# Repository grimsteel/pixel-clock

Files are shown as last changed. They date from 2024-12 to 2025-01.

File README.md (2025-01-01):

# The Pixel Clock

A clock-shaped PCB with 8 Neopixels and a buzzer. Built on a `CH552` MCU. Powered by two rechargeable LIR2032s.

Although this cannot actually be used as a clock, it can be used to play songs, with the neopixels flashing in sync.

Firmware using [ch554_sdcc](https://github.com/Blinkinlabs/ch554_sdcc) is in the firmware directory.

[gerber.zip](https://gerber.zip/2d/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)

---

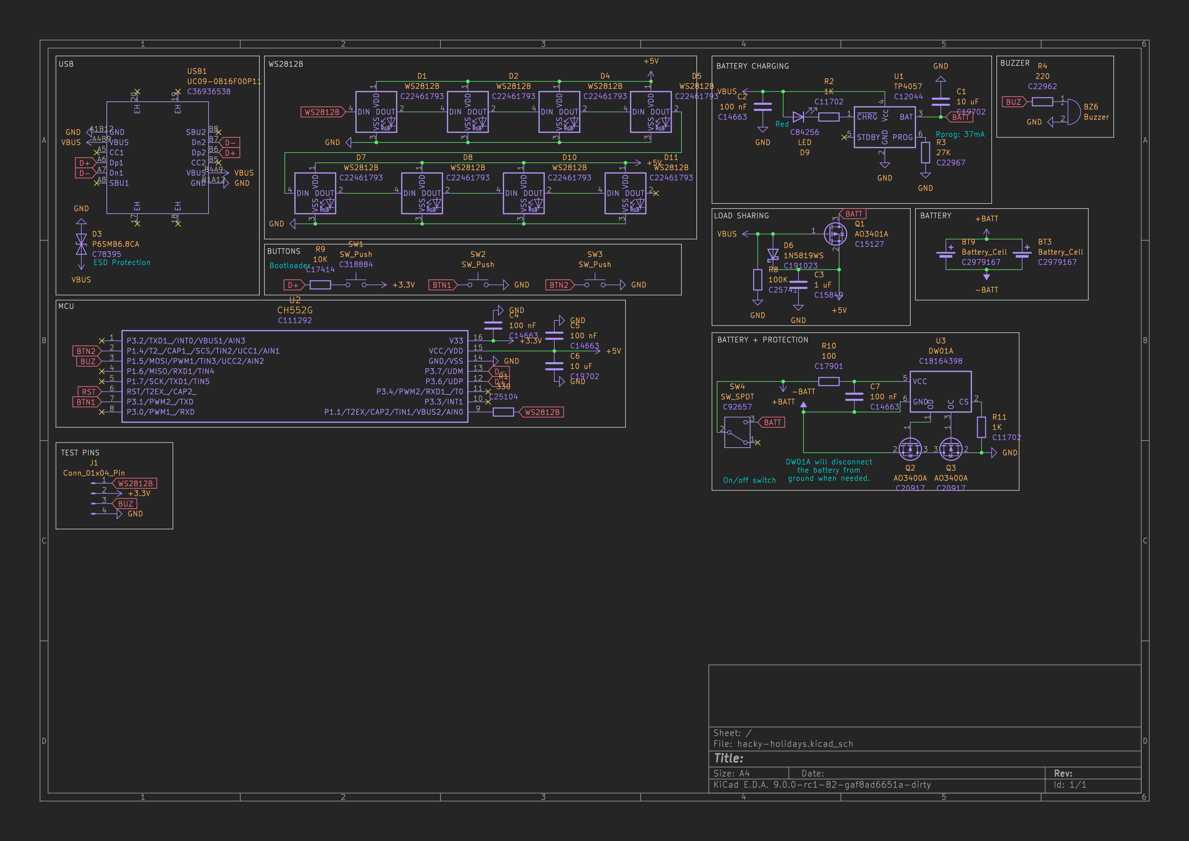
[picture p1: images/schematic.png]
schematic


gerber - top
gerber - bottom

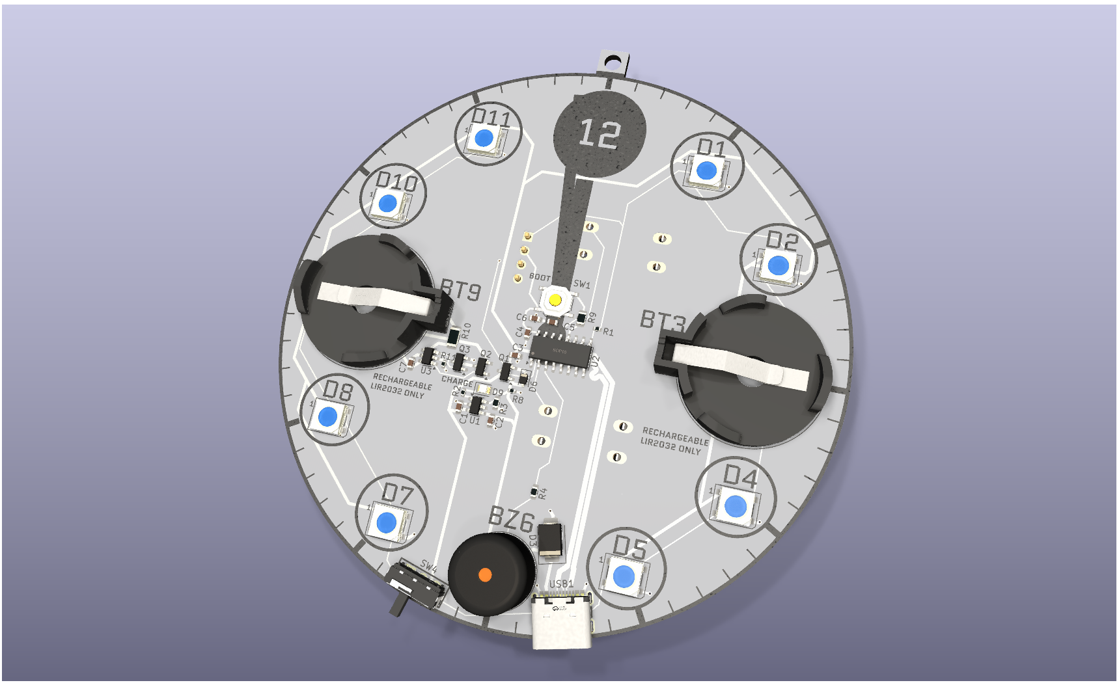
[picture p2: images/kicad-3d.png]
kicad 3d


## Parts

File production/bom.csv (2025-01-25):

Designator | Footprint | Quantity | Value | LCSC Part #
BT3, BT9 | BatteryHolder_MYOUNG_BS-07-A1BJ001_CR2032 | 2 | Battery_Cell | C2979167
C1, C6 | 0603 | 2 | 10 uF | C19702
C2, C4, C5, C7 | 0603 | 4 | 100 nF | C14663
C3 | 0603 | 1 | 1 uF | C15849
D1, D10, D11, D2, D4, D5, D7, D8 | LED-SMD_4P-L1.6-W1.5_XL-1615RGBC-WS2812B | 8 | WS2812B | C5349954
D3 | D_SMB | 1 | P6SMB6.8CA | C78395
D6 | D_SOD-323 | 1 | 1N5819WS | C191023
D9 | 0805 | 1 | LED | C84256
Q1 | SOT-23 | 1 | AO3401A | C15127
Q2, Q3 | SOT-23 | 2 | AO3400A | C20917
R1 | 0402 | 1 | 330 | C25104
R10 | 1206 | 1 | 100 | C17901
R11, R2 | 0402 | 2 | 1K | C11702
R3 | 0603 | 1 | 27K | C22967
R4 | 0603 | 1 | 220 | C22962
R5, R6 | 0603 | 2 | 5.1K | C23186
R8 | 0402 | 1 | 100K | C25741
R9 | 0805 | 1 | 10K | C17414
SW1 | SW_Push_1P1T_XKB_TS-1187A | 1 | SW_Push | C318884
U1 | SOT-23-6 | 1 | TP4057 | C12044
U2 | STC_SOP-16_3.9x9.9mm_P1.27mm | 1 | CH552G | C111292
U3 | SOT-23-6 | 1 | DW01A | C18164398
USB1 | USB-C_UC09-0B16F00P11 | 1 | UC09-0B16F00P11 | C36936538

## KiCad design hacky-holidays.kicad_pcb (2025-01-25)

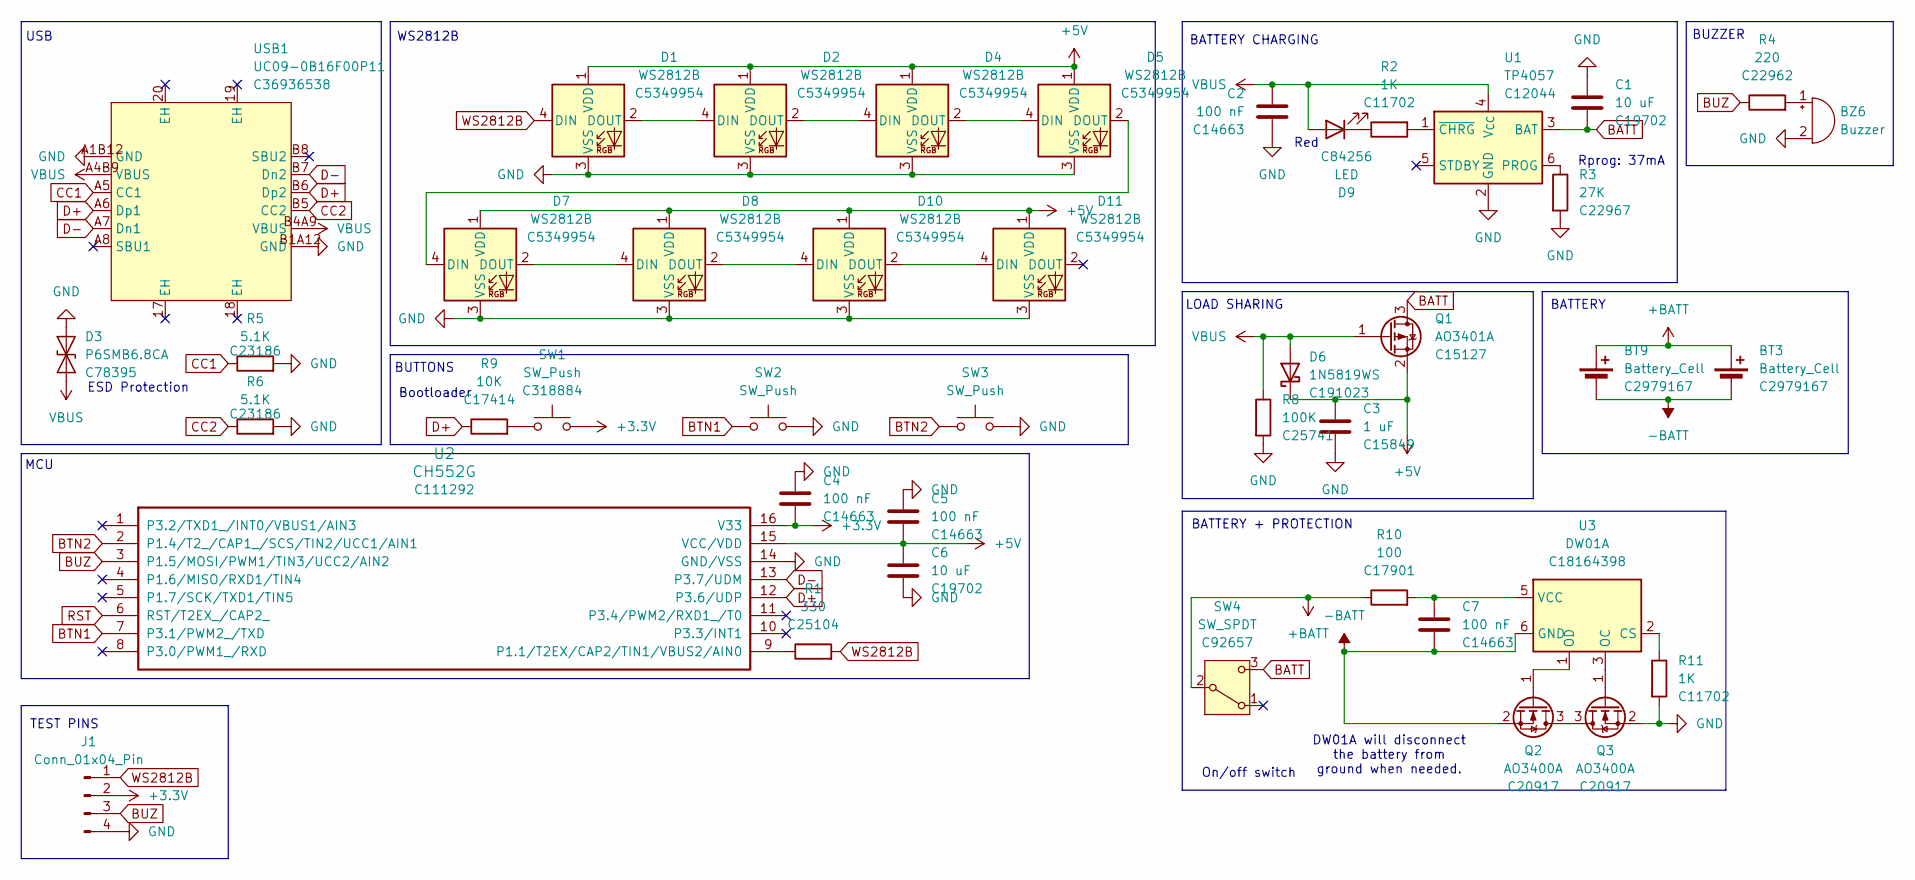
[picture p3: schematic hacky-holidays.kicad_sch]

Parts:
BT3, BT9: Battery_Cell; BatteryHolder_MYOUNG_BS-07-A1BJ001_CR2032; LCSC C2979167
BZ6: Buzzer; Buzzer_12x9.5RM7.6
C1, C6: 10 uF; C_0603_1608Metric; LCSC C19702
C2, C4, C5, C7: 100 nF; C_0603_1608Metric; LCSC C14663
C3: 1 uF; C_0603_1608Metric; LCSC C15849
D1, D2, D4, D5, D7, D8, D10, D11: WS2812B; LED-SMD_4P-L1.6-W1.5_XL-1615RGBC-WS2812B; LCSC C5349954
D3: P6SMB6.8CA; D_SMB; LCSC C78395
D6: 1N5819WS; D_SOD-323; LCSC C191023
D9: LED; LED_0805_2012Metric; LCSC C84256
J1: Conn_01x04_Pin; PinHeader_1x04_P2.54mm_Vertical
Q1: AO3401A; SOT-23; LCSC C15127
Q2, Q3: AO3400A; SOT-23; LCSC C20917
R1: 330; R_0402_1005Metric; LCSC C25104
R2, R11: 1K; R_0402_1005Metric; LCSC C11702
R3: 27K; R_0603_1608Metric; LCSC C22967
R4: 220; R_0603_1608Metric; LCSC C22962
R5, R6: 5.1K; R_0603_1608Metric; LCSC C23186
R8: 100K; R_0402_1005Metric; LCSC C25741
R9: 10K; R_0805_2012Metric; LCSC C17414
R10: 100; R_1206_3216Metric; LCSC C17901
SW1: SW_Push; SW_Push_1P1T_XKB_TS-1187A; LCSC C318884
SW2, SW3: SW_Push; SW_PUSH-12mm
SW4: SW_SPDT; SW-TH_K3-1260D-L1; LCSC C92657
U1: TP4057; SOT-23-6; LCSC C12044
U2: CH552G; STC_SOP-16_3.9x9.9mm_P1.27mm; LCSC C111292
U3: DW01A; SOT-23-6; LCSC C18164398
USB1: UC09-0B16F00P11; USB-C_UC09-0B16F00P11; LCSC Part C36936538

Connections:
+3.3V: C4.2, J1.2, SW1.2, U2.16 (V33)
+5V: C3.1, C5.1, C6.2, D1.1 (VDD), D2.1 (VDD), D4.1 (VDD), D5.1 (VDD), D6.1 (K), D7.1 (VDD), D8.1 (VDD), D10.1 (VDD), D11.1 (VDD), Q1.2 (S), U2.15 (VCC/VDD)
+BATT: BT3.1 (+), BT9.1 (+), R10.1, SW4.2 (B)
-BATT: BT3.2 (-), BT9.2 (-), C7.2, Q2.2 (S), U3.6 (GND)
BATT: C1.2, Q1.3 (D), SW4.3 (C), U1.3 (BAT)
BTN1: SW2.1, U2.7 (P3.1/PWM2_/TXD)
BTN2: SW3.1, U2.2 (P1.4/T2_/CAP1_/SCS/TIN2/UCC1/AIN1)
BUZ: J1.3, R4.1, U2.3 (P1.5/MOSI/PWM1/TIN3/UCC2/AIN2)
CC1: R5.1, USB1.A5 (CC1)
CC2: R6.1, USB1.B5 (CC2)
D+: R9.1, U2.12 (P3.6/UDP), USB1.A6 (Dp1), USB1.B6 (Dp2)
D-: U2.13 (P3.7/UDM), USB1.A7 (Dn1), USB1.B7 (Dn2)
GND: BZ6.2 (-), C1.1, C2.2, C3.2, C4.1, C5.2, C6.1, D1.3 (VSS), D2.3 (VSS), D3.2 (A2), D4.3 (VSS), D5.3 (VSS), D7.3 (VSS), D8.3 (VSS), D10.3 (VSS), D11.3 (VSS), J1.4, Q3.2 (S), R3.2, R5.2, R6.2, R8.2, R11.2, SW2.2, SW3.2, U1.2 (GND), U2.14 (GND/VSS), USB1.A1B12 (GND), USB1.B1A12 (GND)
unnamed: BZ6.1 (+), R4.2
unnamed: D1.2 (DOUT), D2.4 (DIN)
unnamed: D2.2 (DOUT), D4.4 (DIN)
unnamed: D4.2 (DOUT), D5.4 (DIN)
unnamed: D5.2 (DOUT), D7.4 (DIN)
unnamed: D7.2 (DOUT), D8.4 (DIN)
unnamed: D9.1 (K), R2.1
unnamed: D8.2 (DOUT), D10.4 (DIN)
unnamed: D10.2 (DOUT), D11.4 (DIN)
unnamed: Q2.3 (D), Q3.3 (D)
unnamed: Q2.1 (G), U3.1 (OD)
unnamed: Q3.1 (G), U3.3 (OC)
unnamed: R9.2, SW1.1
unnamed: R3.1, U1.6 (PROG)
unnamed: R2.2, U1.1 (~CHRG)
unnamed: R1.1, U2.9 (P1.1/T2EX/CAP2/TIN1/VBUS2/AIN0)
unnamed: R11.1, U3.2 (CS)
unnamed: C7.1, R10.2, U3.5 (VCC)
RST: U2.6 (RST/T2EX_/CAP2_)
VBUS: C2.1, D3.1 (A1), D6.2 (A), D9.2 (A), Q1.1 (G), R8.1, U1.4 (V_{CC}), USB1.A4B9 (VBUS), USB1.B4A9 (VBUS)
WS2812B: D1.4 (DIN), J1.1, R1.2

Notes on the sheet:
Bootloader
On/off switch
MCU
BATTERY
DW01A will disconnect the battery from ground when needed.
Rprog: 37mA
BUZZER
Red
USB
BUTTONS
BATTERY CHARGING
BATTERY + PROTECTION
TEST PINS
LOAD SHARING
WS2812B
ESD Protection

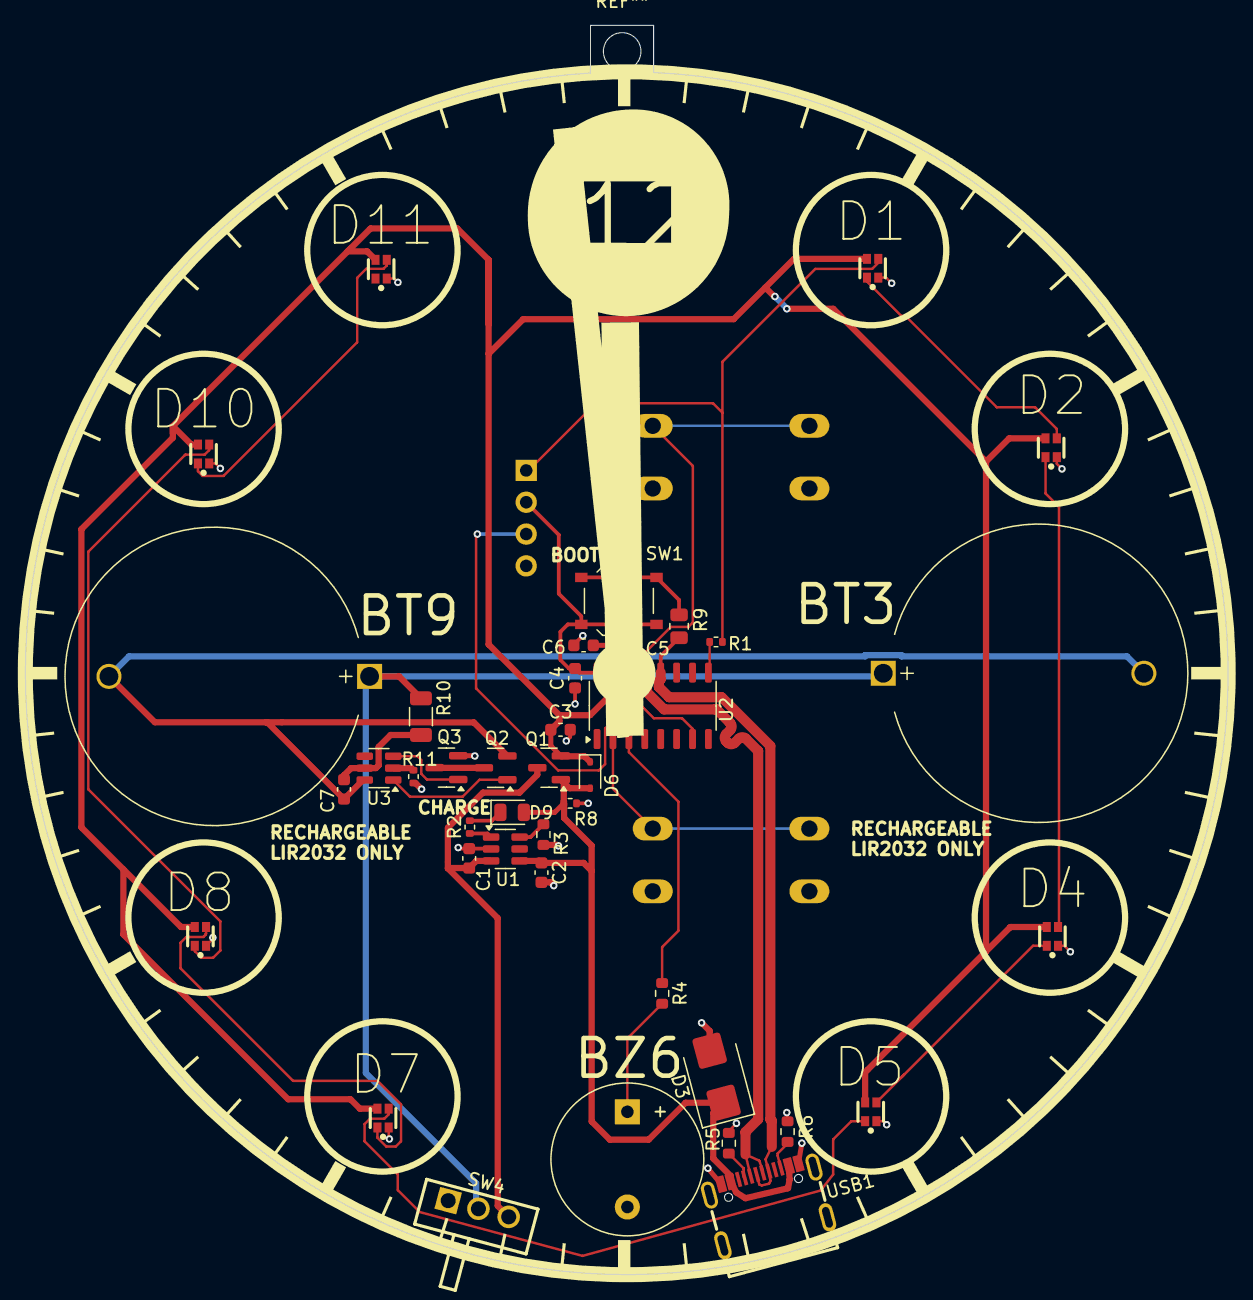
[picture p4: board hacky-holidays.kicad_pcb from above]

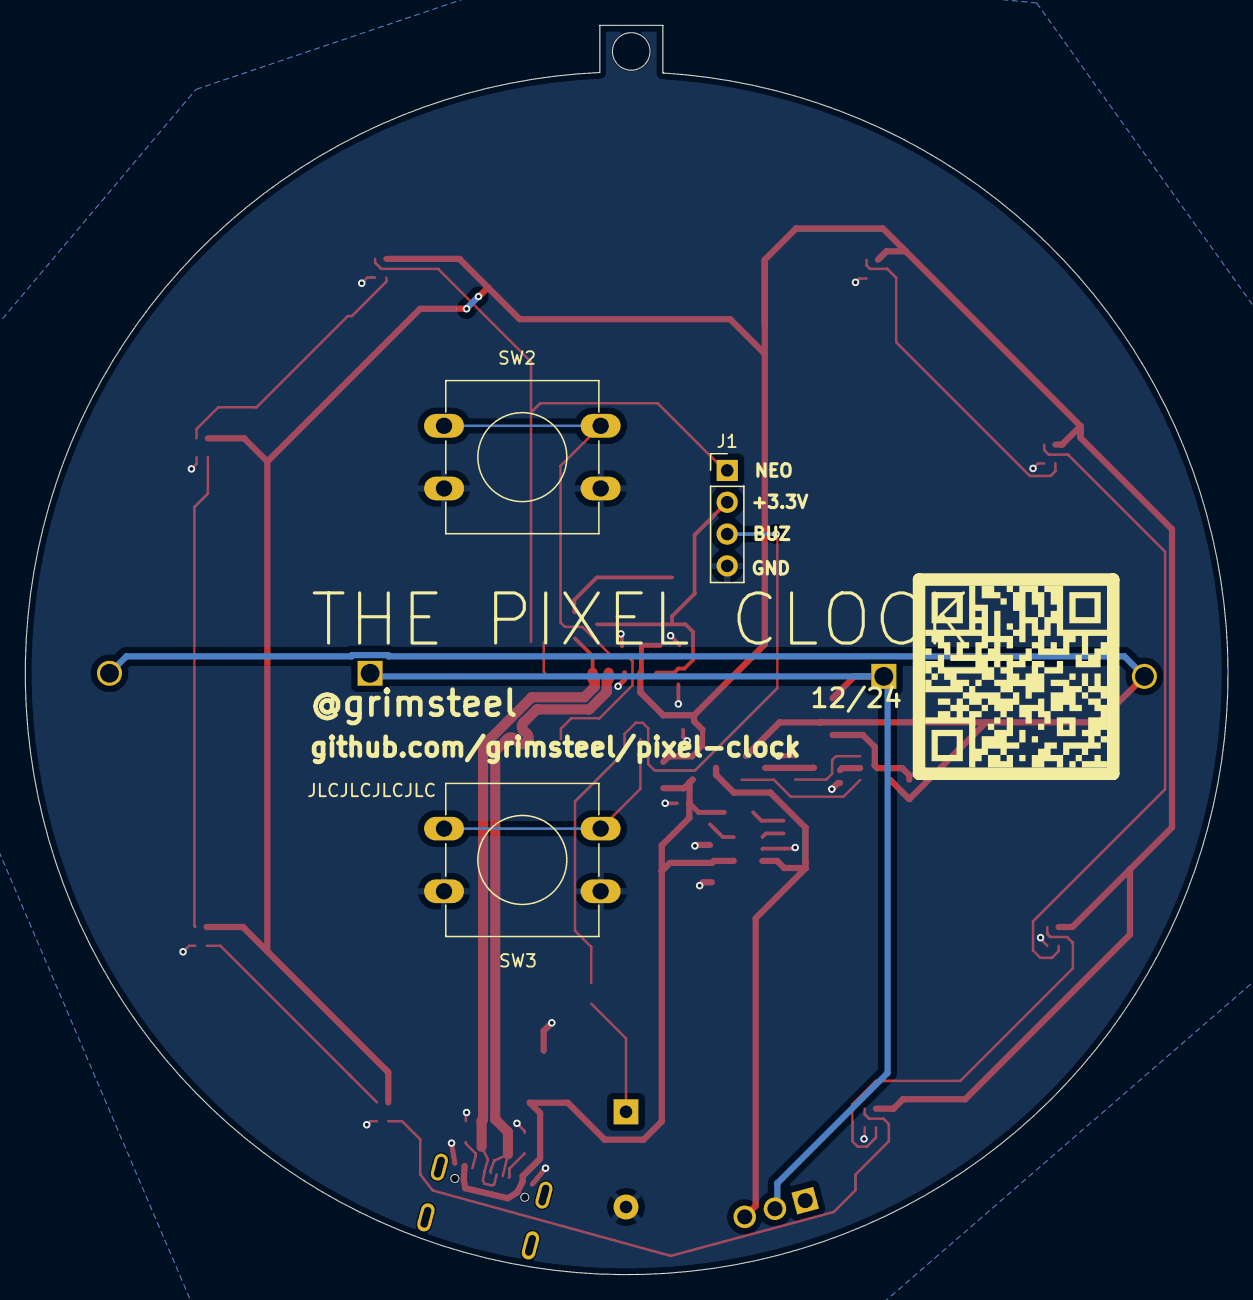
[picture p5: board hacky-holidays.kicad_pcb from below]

Board: 2 copper layers, 96.0 x 99.7 mm, 44 parts (4 on the bottom side), 33 nets.

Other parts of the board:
QR*****: https://github.com/grimsteel/pixel-clock; qrcode

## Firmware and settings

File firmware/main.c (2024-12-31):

#ifndef bool
#define bool int
#endif

#include "ch554.h"
#include "debug.h"
#include "programs.h"

#define P1 0x90
#define P3 0xB0

// setup buttons

// BTN1: P3.1
// BTN2: P1.4
#define BTN1_PIN 1
#define BTN2_PIN 4
SBIT(BTN1, P3, BTN1_PIN);
SBIT(BTN2, P1, BTN2_PIN);

// BUZ: P1.5
#define BUZ_PIN 5
SBIT(BUZ, P1, BUZ_PIN);

// WS2812B: P1.1
#define WS2812B_PIN 1
#define NUM_WS2812B 8
SBIT(WS2812B, P1, WS2812B_PIN);

// [0, 256)
#define WS2812B_BRIGHTNESS 51

// GRB, in order
uint8_t ws2812b_data[NUM_WS2812B * 3];

// Timer frequency in hertz (6 MHz / 12)
#define TIMER_FREQUENCY 500000
#define HALF_TIMER_FREQUENCY 250000

uint16_t timer_ticks_start;
uint32_t toggle_count;
// this serves as the current time.
// 1 "unit" of timer1_overflows is 0.5ms
volatile uint32_t timer1_overflows = 0;
uint32_t last_button1_press = 0;
uint32_t last_button2_press = 0;
volatile uint8_t current_idx = 0;

void next_program_item();

// PWM timer interrupt
void timer0_interrupt(void) __interrupt(INT_NO_TMR0) {
  // one-half cycle has elapsed
  TL0 = timer_ticks_start & 0xff;
  TH0 = timer_ticks_start >> 8;

  if (toggle_count-- > 0) {
    // toggle pin
    BUZ = !BUZ;
  } else {
    // turn off
    BUZ = 0;
    // stop the timer, disable interrupt
    TMOD &= ~bT0_M0;
    TR0 = 0;

    // wait 100ms before next item
    mDelaymS(100);
    next_program_item();
  }
}

// Main timer interrupt
void timer1_interrupt(void) __interrupt(INT_NO_TMR1) { timer1_overflows++; }

inline void btn1_press() {}
inline void btn2_press() {}

// GPIO interurpt
void gpio_interrupt(void) __interrupt(INT_NO_GPIO) {
  if (!BTN1) {
    // if last_button1_press < timer1_overflows, the program has been running for 25 days, and we overflowed the unsigned int
    if (last_button1_press < timer1_overflows && timer1_overflows - last_button1_press >= 20) {
      btn1_press();
    }
    last_button1_press = timer1_overflows;
  }

  if (!BTN2) {
    if (last_button2_press < timer1_overflows && timer1_overflows - last_button2_press >= 20) {
      btn2_press();
    }
    last_button2_press = timer1_overflows;
  }
}

// PWM - 50% duty cycle
// Builtin PWM is too fast for audible tones
// Duration is measured in 16th notes (250ms)
void tone(uint16_t frequency_hz, uint8_t duration) {
  // already playing a tone
  if (TR0 == 1) return;
  
  // TODO: Higher frequencies may be able to use a faster clock (bT0_CLK, bTMR_CLK)

  ET0 = 1; // timer0 interrupt
  TMOD |= bT0_M0; // 16 bit timer0

  // Adapted from arduino tone() code
  // TIMER_FREQUENCY / frequency_hz returns number of ticks for a full cycle
  // Because this is 50% duty cycle, divide by 2 for number of ticks for each "high" or each "low"
  // We will start counting at this value, and go to 0xffff
  // idk what the +1 is for
  timer_ticks_start = 0xffff - (uint16_t) ((uint32_t) (HALF_TIMER_FREQUENCY) / frequency_hz) + 1;
  // frequency * duration = number of full cycles
  // * 2 = number of toggles
  // / 1000 because ms
  // toggle_count = (uint32_t) (frequency_hz * duration_ms) / 1000 * 2;
  // optimized version: measure duration as 1/4 second
  toggle_count = frequency_hz * duration >> 1;

  // Set the timer
  TL0 = timer_ticks_start & 0xff;
  TH0 = timer_ticks_start >> 8;

  TR0 = 1; // begin timer
}

void ws2812b_write() {
  // disable interrupts (time sensitive!)
  E_DIS = 1;
  for (uint8_t i = 0; i < NUM_WS2812B * 3; i++) {
    // TIMINGS AT 6MHz (tolerance 150 ns aka 1 clock cycle)
    // T1H = 0.8 us --> 4-5 clock cycles
    // T1L = 0.45 us --> 2-3 clock cycles
    // T0H = 0.4 us -> 2-3 clock cycles
    // T0L = 0.85 us --> 5-6 clock cycles
    // The low times don't _really_ matter - only the high times matter for distinguishing between 0s and 1s
    // RESET TIME: > 50 us --> 300 clock cycles
    // Total time: 7/8 clock cycles
    // TODO: Tune with a logic analyzer
    __asm
    mov a, r7 ; i is stored in r7
    add a, #_ws2812b_data ; ws2812b_data[i]
    mov r6, #8 ; eight bits
01$:            ; --- loop
    rlc a           ; 1 cycle
    setb _WS2812B   ; 1 cycle - T1H begin + T0H begin + T0L end (2 + 1 + 2 + 1) + T1L end (1 + 2 + 1)
    nop             ; 1 cycle
    mov _WS2812B, c ; 2 cycles - T0H end (1 + 1) + T0L begin
    clr _WS2812B    ; 1 cycle - T1H end (1 + 1 + 2) + T1L begin
    djnz r6, 01$    ; 2 cycles
    __endasm;
  }
  // re-enable interrupts
  E_DIS = 0;
}

// Hues is an array of length NUM_WS2812B
void ws2812b_set_hues(uint16_t *hues) {
  for (int i = 0; i < NUM_WS2812B; i++) {
    uint16_t hue = hues[i];
    uint8_t r = 0, g = 0, b = 0;
    uint8_t sector = hue / 60;
    switch (sector) {
    case 5: // [300, 360)
      r = WS2812B_BRIGHTNESS;
      b = WS2812B_BRIGHTNESS * 6 - WS2812B_BRIGHTNESS * hue / 60;
      break;
    case 0: // [0, 60)
      r = WS2812B_BRIGHTNESS;
      g = WS2812B_BRIGHTNESS * hue / 60;
      break;
      
    case 1: // [60, 120)
      g = WS2812B_BRIGHTNESS;
      r = WS2812B_BRIGHTNESS * 2 - WS2812B_BRIGHTNESS * hue / 60;
      break;
    case 2:
      g = WS2812B_BRIGHTNESS;
      b = WS2812B_BRIGHTNESS * hue / 60 - WS2812B_BRIGHTNESS * 2;
      break;
      
    case 3:
      b = WS2812B_BRIGHTNESS;
      g = WS2812B_BRIGHTNESS * 4 - WS2812B_BRIGHTNESS * hue / 60;
      break;
    case 4:
      b = WS2812B_BRIGHTNESS;
      r = WS2812B_BRIGHTNESS * hue / 60 - WS2812B_BRIGHTNESS * 4;
      break;
    }
    ws2812b_data[i * 3] = g;
    ws2812b_data[i * 3 + 1] = r;
    ws2812b_data[i * 3 + 2] = b;
  }
}

void next_program_item() {
  if (current_idx == PROGRAM1_LENGTH)  {
    // wait 1 second before repeating
    current_idx = 0;
    mDelaymS(1000);
  }
  uint16_t hues[NUM_WS2812B];
  for (int j = 0; j < NUM_WS2812B; j++) {
    hues[j] = program_1_hues[current_idx];
  }
  ws2812b_set_hues(hues);
  ws2812b_write();
  
  // buzzer
  tone(program_1_notes[current_idx], program_1_durations[current_idx]);
  current_idx++;
}

void main() {
  // frequency is default (6MHz)
  // CfgFsys(); no need for this
  mDelaymS(5);

  /*// enter safe mode
  SAFE_MOD = 0x55;
  SAFE_MOD = 0xAA;
  
  // setup sleep wake on buttons
  WAKE_CTRL |= bWAK_P1_4_LO | bWAK_P3_2E_3L; // 3.2 is disconnected

  // exit safe mode
  SAFE_MOD = 0x00;*/

  mInitSTDIO();
  UART1Setup();

  // disable all pullups except for 1.2 and 1.3 (clock)
  P1_DIR_PU &= 0x0C;
  // disable all except for 3.6 and 3.7 (usb)
  P3_DIR_PU &= 0xC0;
  
  // push pull mode
  P1_MOD_OC &= ~(1 << WS2812B_PIN);
  // enable pullup
  P1_DIR_PU |= 1 << WS2812B_PIN;
  

  P1_MOD_OC &= ~(1 << BUZ_PIN);
  P1_DIR_PU |= 1 << BUZ_PIN;
  BUZ = 0;

  // configure buttons as high impedance with pullup
  P1_MOD_OC |= 1 << BTN2_PIN;
  P1_DIR_PU |= 1 << BTN2_PIN;

  P3_MOD_OC |= 1 << BTN1_PIN;
  P3_DIR_PU |= 1 << BTN1_PIN;

  // enable interrupts
  EA = 1;
  // gpio interrupts
  IE_GPIO = 1;
  // gpio edge interrupt mode, enable on 1.4 and 3.1
  GPIO_IE |= bIE_IO_EDGE | bIE_P1_4_LO | bIE_P3_1_LO;

  ET1 = 1; // timer0 interrupt
  TMOD |= bT1_M1;// 8 bit timer1 (0.5 ms for each overflow - 256 / (6 MHz / 12) = 512 us)
  TR1 = 1;

  // start program
  next_program_item();
}

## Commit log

2024-12-28 add remaining neopixel lcsc ids
    [hacky-holidays.kicad_pcb]
2024-12-28 add clock outline
    [hacky-holidays.kicad_pcb]
2024-12-28 add usb lcsc part
    [hacky-holidays.kicad_pcb]
2024-12-28 add production files
    [bom.csv, designators.csv, positions.csv]
2024-12-31 update capacitor part numbers, add test pins, silkscreen updates
    [bom.csv, designators.csv, hacky-holidays.kicad_pcb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]
2024-12-31 tidy schematic
    [hacky-holidays.kicad_pcb, hacky-holidays.kicad_sch]
2024-12-31 add mounting hole
    [designators.csv, hacky-holidays.kicad_pcb]
2025-01-01 add schematic image
2025-01-01 make pcb below 100x100
    [hacky-holidays.kicad_pcb]
2025-01-02 invert qr code
    [hacky-holidays.kicad_pcb]
2025-01-02 add usb cc resistors
    [bom.csv, designators.csv, hacky-holidays.kicad_pcb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]
2025-01-24 use economic ws2812bs
    [bom.csv, designators.csv, hacky-holidays.kicad_pcb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]
2025-01-25 fix designators
    [bom.csv, designators.csv, hacky-holidays.kicad_pcb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]
